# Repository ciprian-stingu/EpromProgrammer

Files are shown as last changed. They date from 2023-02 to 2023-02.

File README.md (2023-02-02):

# EpromProgrammer
2716 through 27080 Eprom Programmer

A programmer for EPROMs with capacities between 2KiB (2716 series) and 1MiB (27C080 series).  
It uses an Arduino NANO and few other components.  
As a starting point I used the excelent [arduino_eprom27_programmer](https://github.com/walhi/arduino_eprom27_programmer) project

## Main features
* It supports a large number of EPROMs with different capacities
* 2 programming speeds (normal & fast). Fast programming speed is available if you configure the VCC correctly
* On fast programming alghoritm, writing a 27C040 EPROM takes around 290 seconds
* Error detection on writing
* Additional verify option

## Hardware
All the files which you need in order to create the PCBs are in the [hardware](hardware) folder.

## Case
The files for 3D printing a case are available in [FreeCAD](FreeCAD) folder

## Limitations in current implementation
* No Windows support, but it should be easy to implement

## Supported EPROMs
```
//------------- 2716 -------------
2716 - Generic, 2716 - AMD, ET2716, HN462716, 2716 - Intel, M2716, M5L2716K, MBM2716, MCM2716, uPD2716
//------------- 27C16 -------------
27C16 - Generic, 27C16 - National, AM2716B, NMC27C16B
//------------- 2732 -------------
2732 - Generic, AM2732, AM9732, F2732, HN462732, 2732A, M2732A, MBM2732, NTE2732A, TMM2732D, uPD2732A
//------------- 27C32 -------------
27C32 - Generic, AM2732B, NMC27C32B, WS57C43C
//------------- 2764 -------------
2764 - Generic, 2764A - Intel, M2764A, M5L2764K, NTE2764, TMM2764AD
//------------- 27C64 -------------
27C64 - Generic, 27C64 - Microchip, Cy7C266, MBM27C64, NMC27C64, TMS27C64
//------------- 27128 -------------
27128 - Generic, HN4827128G, HN27128, M27128A - Intel, M27128A - ST, M5L27128K, M5M27C128K, MBM27128, NTE21128, TMM27128AD, TMS27128, uPD27128
//------------- 27C128 -------------
27C128 - Generic, 27C128 - Microchip, AM27C128, AT27C128, CY27C128, LH57126, M27C128, MSM27C128, NM27C128 - Fairchild, NM27C128 - National, QP27C128, SMJ27C128, TMS27C128
//------------- 27256 -------------
27256 - Generic, A68C256, AT27256, 27256 - Intel, M5L27256K, MBM27256, MSM27256, TMM27256, uPD27256
//------------- 27C256 -------------
27C256 - Generic, 27C256 - Microchip, AM27C256, AM27H256, CXK27C256DQ, CY27C256, CY27H256, CY7C274, EM27C256, FM27C256, HN27C256A, HN27C256AG, IS27C256, M27C256B, M5M27C256K, MBM27C256, 27HC256, MSM27C256H, NM27C256 - Fairchild, NM27C256 - National, NM27LC256, NMC27C256, NMC87C257, NPX27C256, QP27C256, 27C256 - SEEQ, M27C256 - SEEQ, SMJ27C256 - ASI, SMJ27C256 - TI, SPM27C256, TC57256, TMS27C256, TMS87C257, uPD27C256
//------------- 27512 -------------
27512 - Generic, 27512 - Intel, AM27512, HN27512, M27512, M5L27512K, MSM27512, TMM27512AD
//------------- 27C512 -------------
27C512 - Generic, 27C512 - Microchip, 27C512 - Intel, 27C512 - Philips, AM27C512, CXK27C512DQ, CY27C512, CY27H512, EM27C512, FM27C512, HN27C512, IS27HC512, MBM27C512, MX27C512, NM27C512, NM27P512, SMJ27C512 - ASI, SMJ27C512 - TI, TC57512AD, TMS27C512, uPD27C512
//------------- 27C010 -------------
27C010 - Generic, AM27C010, AM27H010, AM27HB010, CY27C010, CY27H010, 27C010 - Intel, EM27C010, FM27C010, HN27C101, IS27C010, M5M27C101K, NM27C010 - Fairchild, NM27C010 - National, NMC27C010, SMJ27C010 - ASI, SMJ27C010 - TI, TMS27C010
//------------- 27C1001 -------------
27C1001 - Generic, CXK27C1001DQ, M27C1001, MBM27C1001, MSM27C1000, MX27C1000, TC57C1001, TC57H1001
//------------- 27C020 -------------
27C020 - Generic, AM27C020, CY27C020, 27C020 - Intel, EM27C020, IS27C020, NM27C020, TMS27C020
//------------- 27C2001 -------------
27C2001 - Generic, M27C2001, MSM27C2000, uPD27C2001
//------------- 27C040 -------------
27C040 - Generic, AM27C040, CY27C040, EM27C040, FM27C040, 27C040 - Intel, NM27C040, NXP27C040, SMJ27C040 - ASI, SMJ27C040 - Micross, SMJ27C040 - TI, TMS27C040
//------------- 27C4001 -------------
27C4001 - Generic, HN27C4001, M27C4001, MBM27C4001, MSM27C401, MX27C4000, TC57C4000, uPD27C4001
//------------- 27C080 -------------
27C080 - Generic, AM27C080, AT27LV080, M27C801, MX27C8000
```

## Programmer images
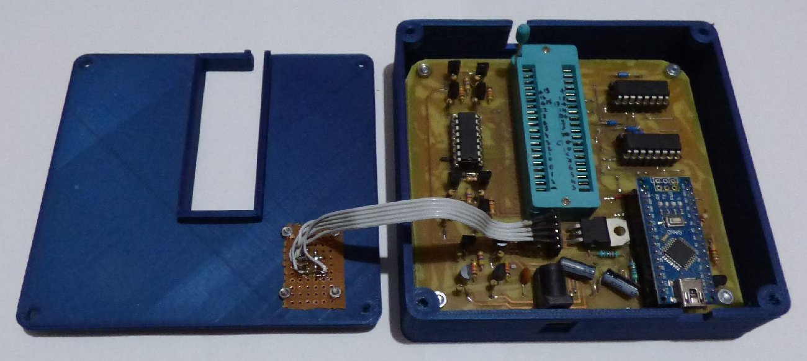
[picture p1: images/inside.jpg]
Inside
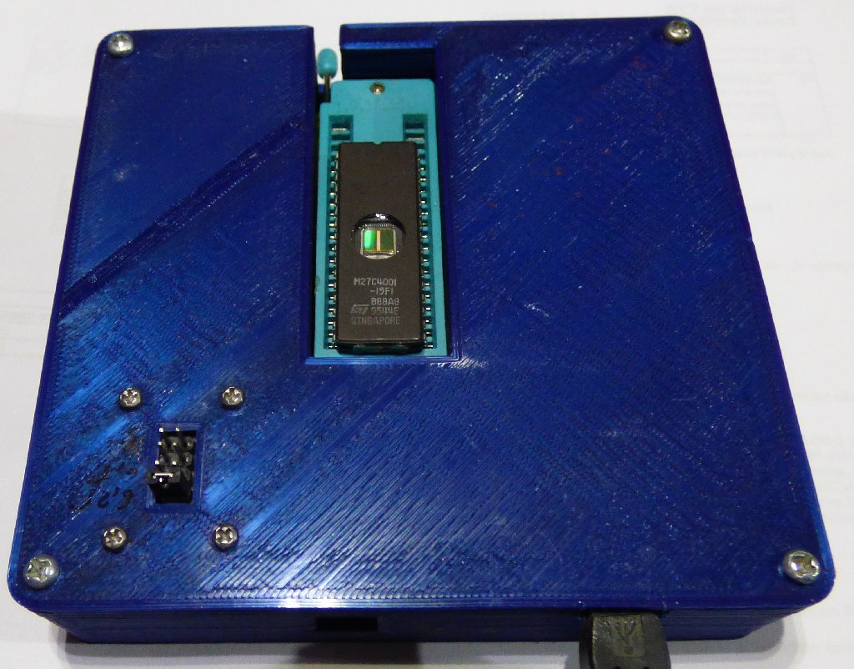
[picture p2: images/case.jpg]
Assembled Programmer
 

## GUI images
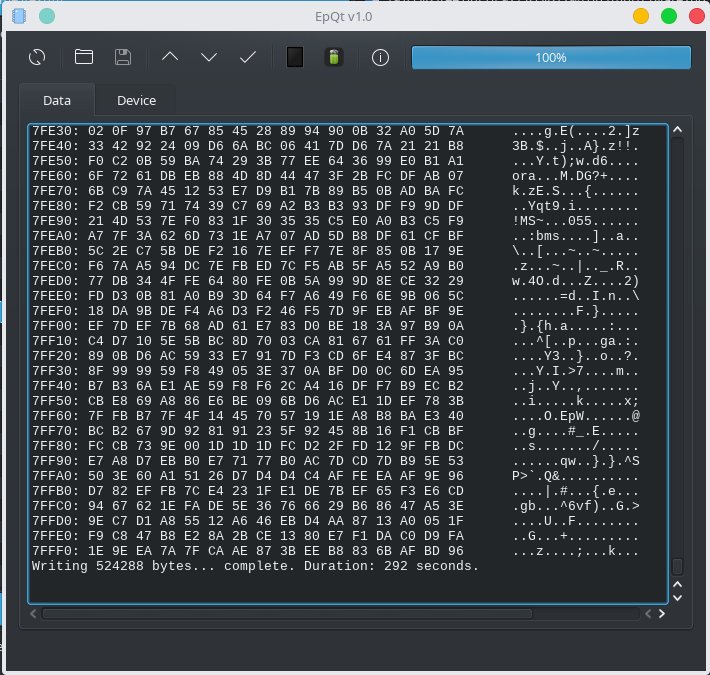
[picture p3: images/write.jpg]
Write
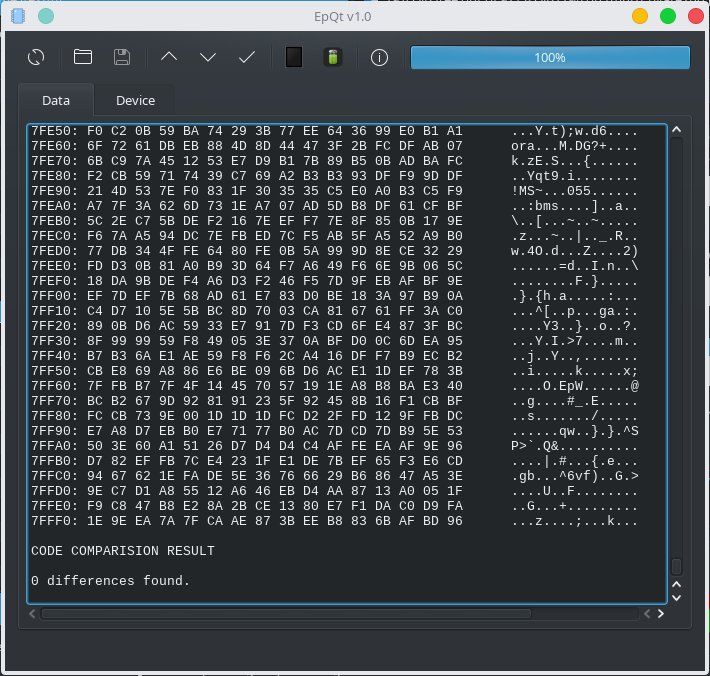
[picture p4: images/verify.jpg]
Verify
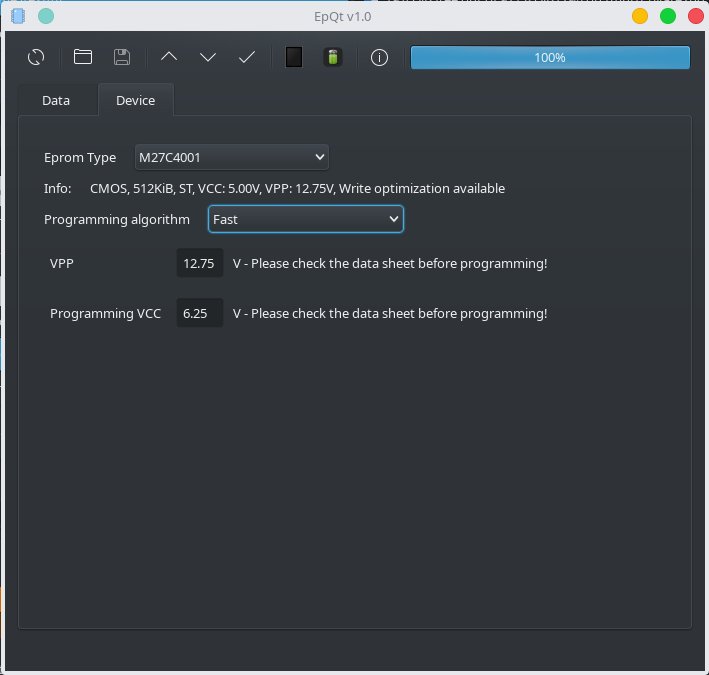
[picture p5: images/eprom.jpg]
EPROM options


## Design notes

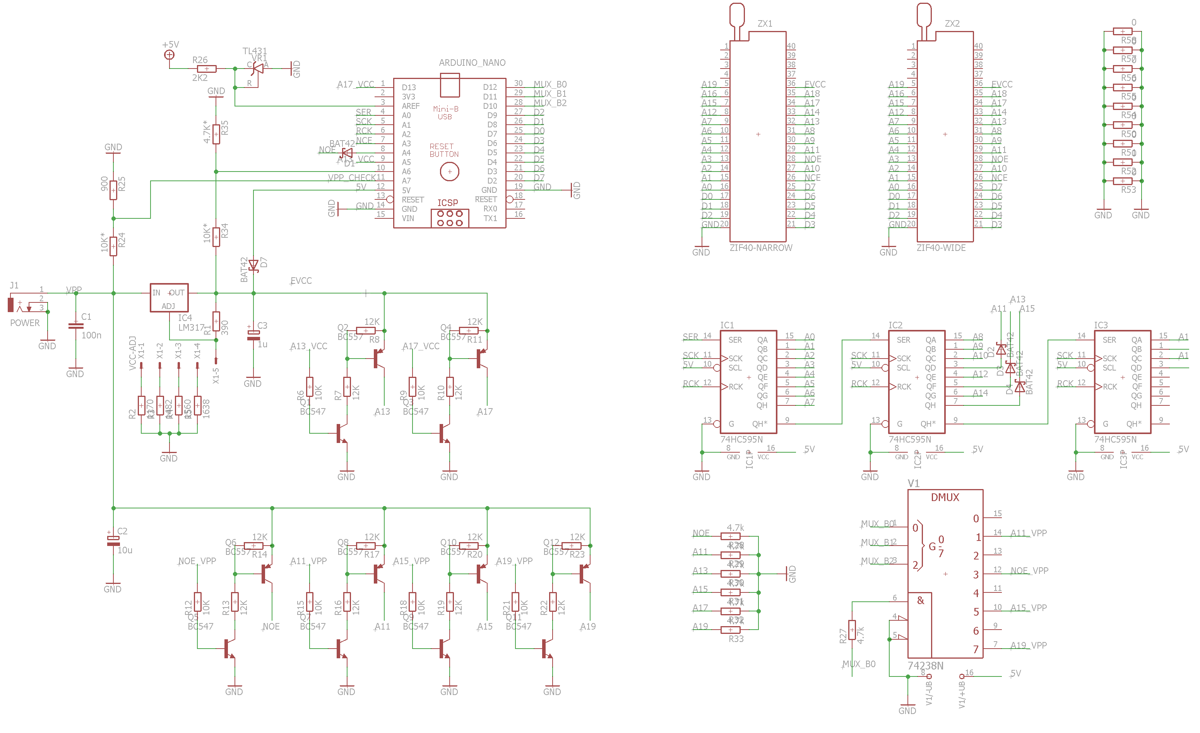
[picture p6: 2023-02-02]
hardware/schematic.png

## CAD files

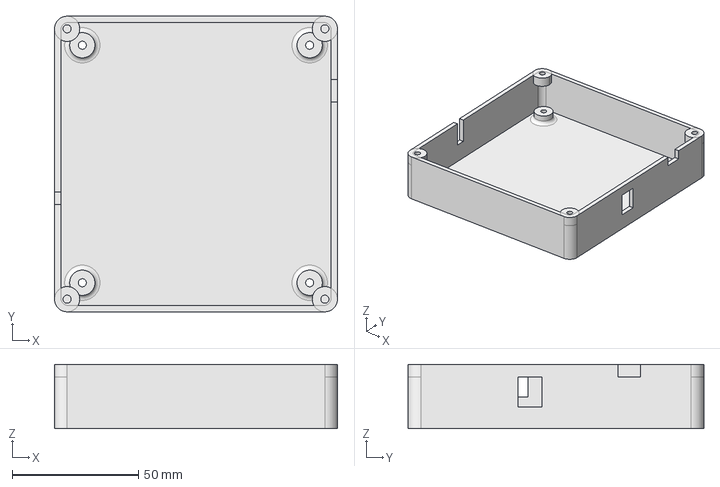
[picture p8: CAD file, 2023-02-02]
FreeCAD/case.FCStd
112.0 x 117.0 x 25.5 mm

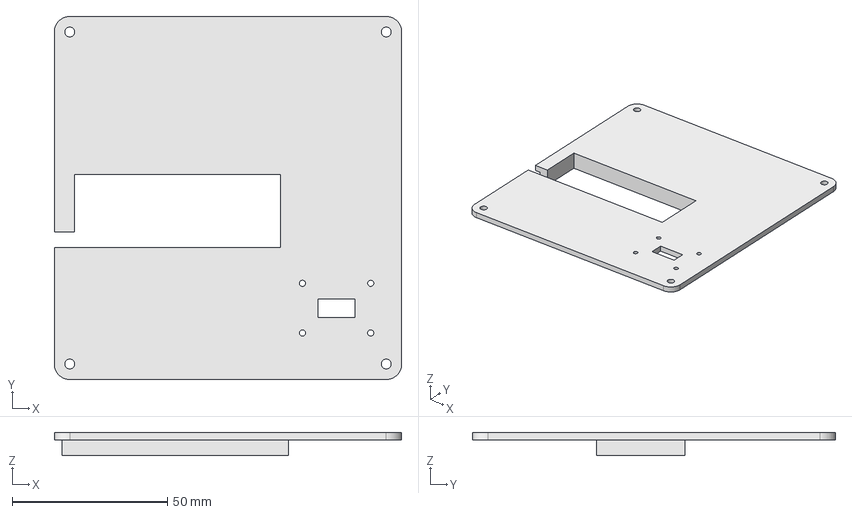
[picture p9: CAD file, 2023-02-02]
FreeCAD/lid.FCStd
112.0 x 117.0 x 7.50 mm

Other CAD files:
FreeCAD/case.stl
FreeCAD/lid.stl

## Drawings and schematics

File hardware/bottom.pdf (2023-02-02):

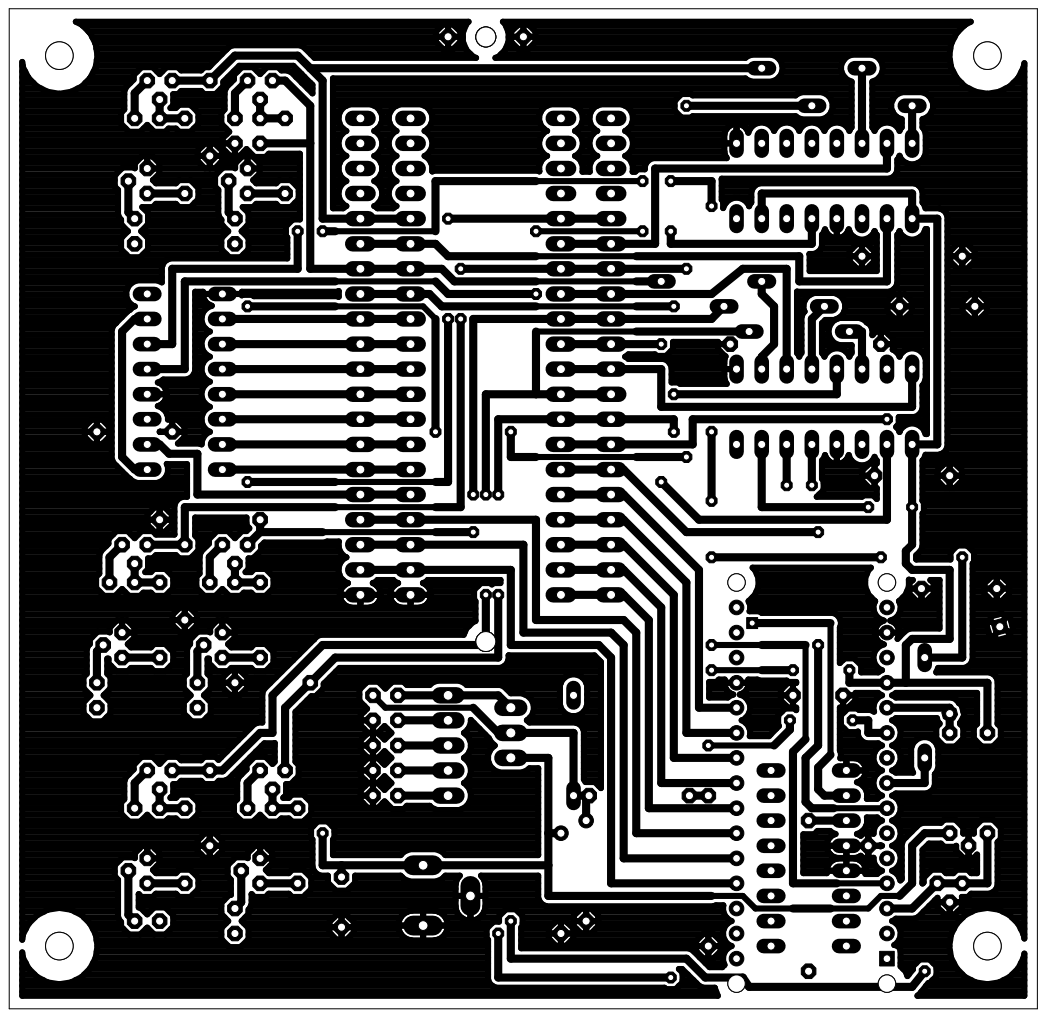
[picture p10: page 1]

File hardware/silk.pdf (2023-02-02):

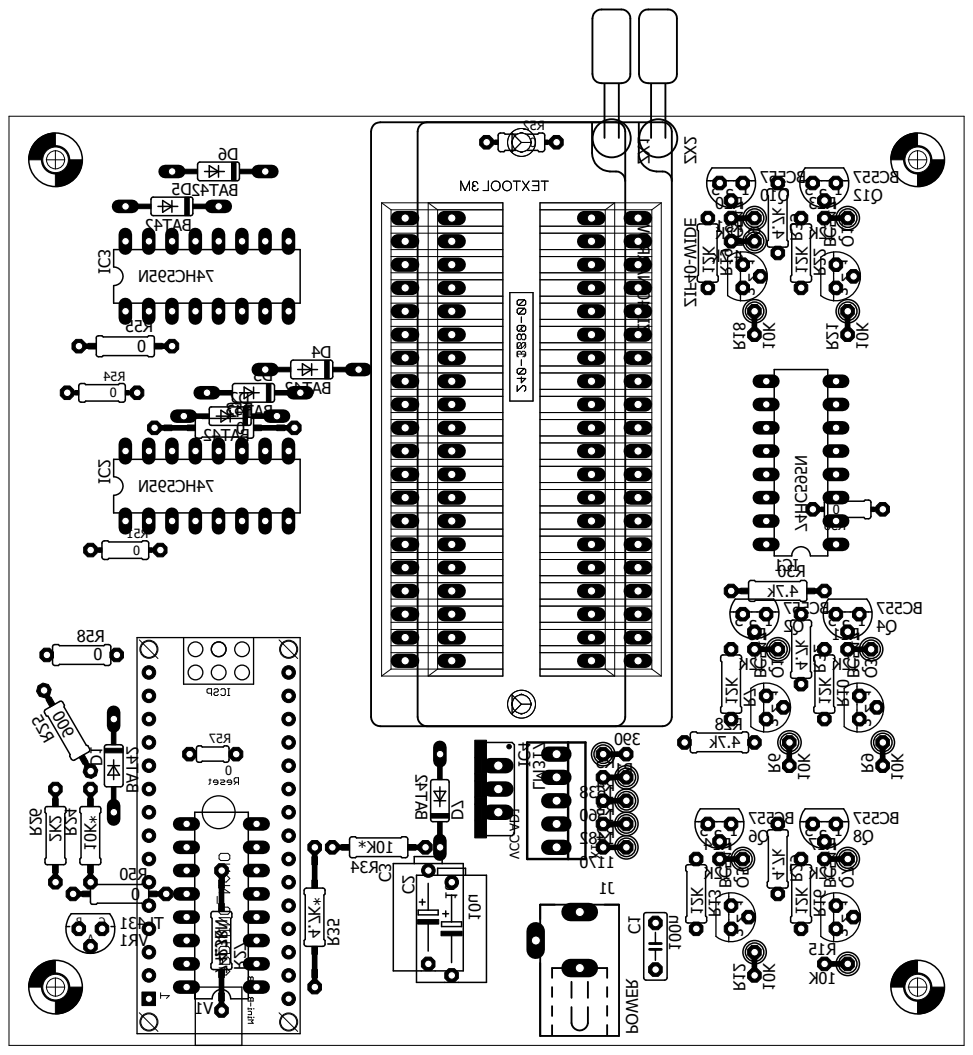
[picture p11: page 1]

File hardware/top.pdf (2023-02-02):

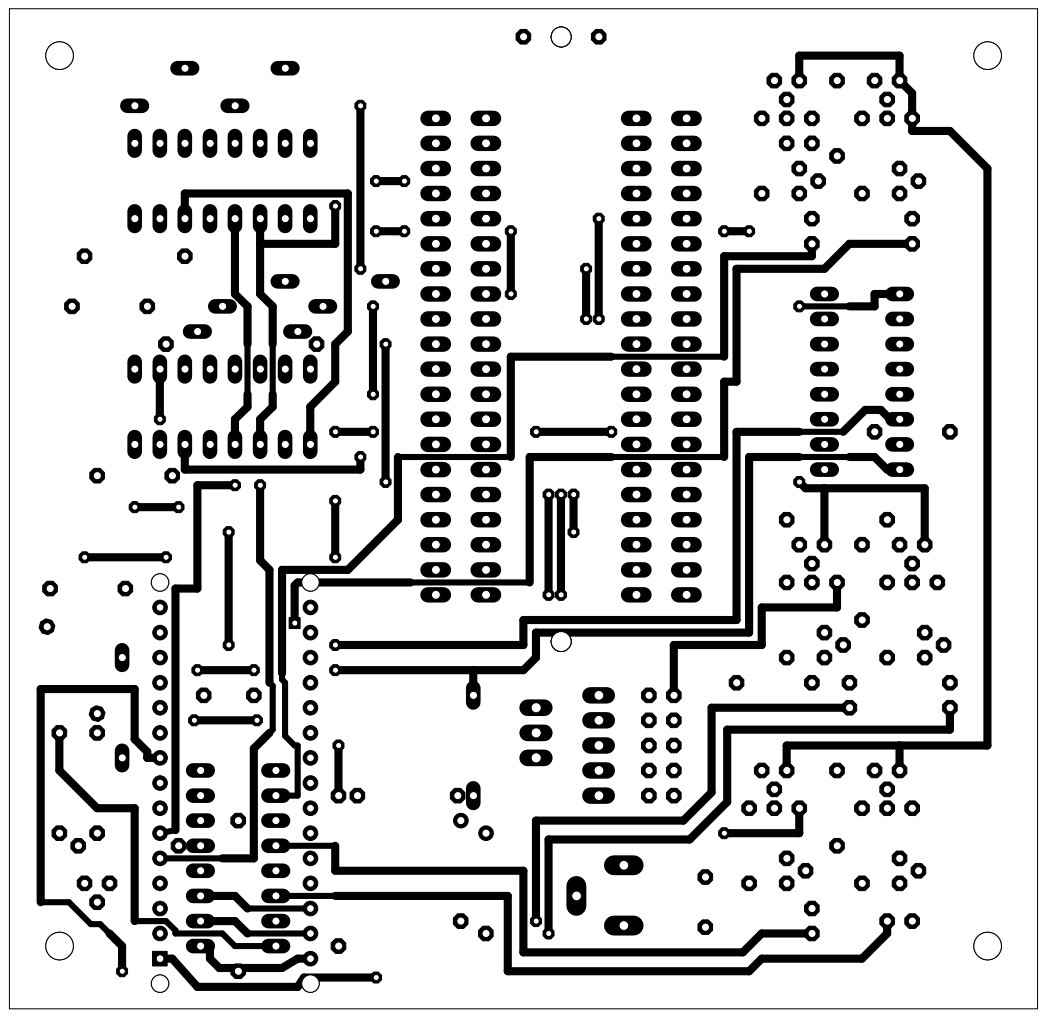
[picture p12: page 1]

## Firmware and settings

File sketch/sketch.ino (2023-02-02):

/**
 * 
 * Eprom Programmer
 * 
 * Copyright (C) 2021-2023 Ciprian Stingu
 * ciprian stingu at gmail dot com
 * 
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
 */
//------------------------------------------------------------------------------
#include "defines.h"
#include "io.h"
#include "write.h"
#include "read.h"
#include "test.h"
//------------------------------------------------------------------------------
// global variables
uint8_t SerialBufferStorage[SERIAL_BUF_LEN + 1];
uint8_t *SerialBuffer = SerialBufferStorage;
COMMAND_MODE CommandMode = COMMAND_MODE::WAIT;
EPROM_TYPE EpromSelected = EPROM_TYPE::NONE;
PRG_ALGO ProgrammingAlgorithm = PRG_ALGO::STANDARD;
double VppRequired = 0.0;
double VccRequired = 0.0;
uint32_t EpromEndAddress = 0; 
uint8_t EpromVppPin = 0;
//------------------------------------------------------------------------------

int8_t StringPos(uint8_t *bytes, const char *test, uint8_t offset = 0);
//------------------------------------------------------------------------------

void setup() 
{
  // set voltage reference to external
  analogReference(EXTERNAL);
  analogRead(VPP_TEST_PIN);
  analogRead(VCC_TEST_PIN);
    
  // 74HC595
  pinMode(SER_PIN, OUTPUT);
  pinMode(SCK_PIN, OUTPUT);
  pinMode(RCK_PIN, OUTPUT);

  pinMode(NCE_PIN, OUTPUT);
  pinMode(NOE_PIN, OUTPUT);
  pinMode(A13_VCC_PIN, OUTPUT);
  pinMode(A17_VCC_PIN, OUTPUT);

  // set mux output
  pinMode(MUX_B0_PIN, OUTPUT);
  pinMode(MUX_B1_PIN, OUTPUT);
  pinMode(MUX_B2_PIN, OUTPUT);
  
  InitializeEpromToAKnownState();

  SerialBuffer[SERIAL_BUF_LEN] = 0x00;
  
  Serial.begin(115200);
  Serial.println(F("27[C]XXXX programmer"));
  Serial.flush();

  CommandMode = COMMAND_MODE::WAIT;
}
//------------------------------------------------------------------------------

void loop() 
{
  switch(CommandMode)
  {
    case COMMAND_MODE::READ:
      if(EpromSelected == EPROM_TYPE::NONE)
      {
        Serial.print(F(RESPONSE_FLAG));
        Serial.print(F(RESPONSE_ERROR));
        Serial.println(F("No EPROM selected!"));
        Serial.flush();
        CommandMode = COMMAND_MODE::WAIT;
        break;
      }
      
      Serial.print(F(RESPONSE_FLAG));
      Serial.println(F(RESPONSE_READ_EPROM));
      Serial.flush();
      
      ReadEprom();

      Serial.print(F(RESPONSE_FLAG));
      Serial.println(F(RESPONSE_OK));
      Serial.flush();
      
      CommandMode = COMMAND_MODE::WAIT;
      break;
      
    case COMMAND_MODE::WRITE:
      if(EpromSelected == EPROM_TYPE::NONE)
      {
        Serial.print(F(RESPONSE_FLAG));
        Serial.print(F(RESPONSE_ERROR));
        Serial.println(F("No EPROM selected!"));
        Serial.flush();
        CommandMode = COMMAND_MODE::WAIT;
        break;
      }
      else if(VccRequired < MIN_VCC || VccRequired > MAX_VCC || VppRequired < MIN_VPP || VppRequired > MAX_VPP) 
      {
        Serial.print(F(RESPONSE_FLAG));
        Serial.print(F(RESPONSE_ERROR));
        Serial.println(F("Invalid VCC/VPP range specified!"));
        Serial.flush();
        CommandMode = COMMAND_MODE::WAIT;
        break;
      }
      else
      {
        double vccVoltage = GetVccVoltage();
        double vppVoltage = GetVppVoltage();
        if(vccVoltage < VccRequired - 0.25 || vccVoltage > VccRequired + 0.25)
        {
          Serial.print(F(RESPONSE_FLAG));
          Serial.print(F(RESPONSE_ERROR));
          Serial.print(F("Vcc: "));
          Serial.print(vccVoltage, 2);
          Serial.print(F("V != "));
          Serial.print(VccRequired, 2);
          Serial.println(F("V"));
          Serial.flush();
          CommandMode = COMMAND_MODE::WAIT;
          break;
        }
        if(vppVoltage < VppRequired - 0.25 || vppVoltage > VppRequired + 0.25)
        {
          Serial.print(F(RESPONSE_FLAG));
          Serial.print(F(RESPONSE_ERROR));
          Serial.print(F("Vpp: "));
          Serial.print(vppVoltage, 2);
          Serial.print(F("V != "));
          Serial.print(VppRequired, 2);
          Serial.println(F("V"));
          Serial.flush();
          CommandMode = COMMAND_MODE::WAIT;
          break;
        }
      }

      Serial.print(F(RESPONSE_FLAG));
      Serial.println(F(RESPONSE_WRITE_EPROM));
      Serial.flush();
      
      {
        if(ProgrammingAlgorithm == PRG_ALGO::STANDARD) {
           Serial.setTimeout(750);
        }
        else {
          Serial.setTimeout(400);
        }
        bool writeResult = WriteEprom();
        Serial.setTimeout(1000);
        EndWriteData();
        
        if(writeResult)
        {
          Serial.print(F(RESPONSE_FLAG));
          Serial.println(F(RESPONSE_WRITE_EPROM));
          Serial.flush();
        }
      }
      
      CommandMode = COMMAND_MODE::WAIT;
      break;
      
    case COMMAND_MODE::VOLTAGE:
      {
        double vccVoltage = GetVccVoltage();
        double vppVoltage = GetVppVoltage();

        Serial.print(F(RESPONSE_FLAG));
        Serial.print(F(RESPONSE_VOLTAGE_INFO));
        Serial.print(F("[VCC] "));
        Serial.print(vccVoltage, 2);
        Serial.print(F("|[VPP] "));
        Serial.println(vppVoltage, 2);
        Serial.flush();
      }
      CommandMode = COMMAND_MODE::WAIT;
      break;
      
    case COMMAND_MODE::TEST: //just to be sure
      if(EpromSelected != EPROM_TYPE::NONE)
      {
        Serial.print(F(RESPONSE_FLAG));
        Serial.print(F(RESPONSE_ERROR));
        Serial.println(F("EPROM is selected!"));
        Serial.flush();
        CommandMode = COMMAND_MODE::WAIT;
        break;
      }
      
      Serial.print(F(RESPONSE_FLAG));
      Serial.print(F(RESPONSE_TEST));
      Serial.println(F(" ON"));
      TestMode();
      Serial.print(F(RESPONSE_FLAG));
      Serial.print(F(RESPONSE_TEST));
      Serial.println(F(" OFF"));
      Serial.flush();
      CommandMode = COMMAND_MODE::WAIT;
      break;

    case COMMAND_MODE::TEST_SPEED: //just to be sure
      if(EpromSelected != EPROM_TYPE::NONE)
      {
        Serial.print(F(RESPONSE_FLAG));
        Serial.print(F(RESPONSE_ERROR));
        Serial.println(F("EPROM is selected!"));
        Serial.flush();
        CommandMode = COMMAND_MODE::WAIT;
        break;
      }
      
      Serial.print(F(RESPONSE_FLAG));
      Serial.print(F(RESPONSE_TEST));
      Serial.println(F(" SPEED ON"));
      TestSpeed();
      Serial.print(F(RESPONSE_FLAG));
      Serial.print(F(RESPONSE_TEST));
      Serial.println(F(" SPEED OFF"));
      Serial.flush();
      CommandMode = COMMAND_MODE::WAIT;
      break;
      
    default:
      if(!Serial.available()) {
        break;
      }

      for(uint8_t i = 0; i < SERIAL_BUF_LEN + 1; i++) {
        SerialBuffer[i] = 0x00;
      }
      
      uint8_t count = Serial.readBytes(SerialBuffer, SERIAL_BUF_LEN);
    
      while(Serial.available()) {
        Serial.read();
      }

      if(count)
      {
        bool commandFound = true;
        int8_t commandFlagIndex = StringPos(SerialBuffer, COMMAND_FLAG);
        
        if(commandFlagIndex != -1)
        {          
          int8_t commandTypeIndex = -1;
          
          if((commandTypeIndex = StringPos(SerialBuffer, COMMAND_SET_EPROM_TYPE, commandFlagIndex + 4)) != -1) 
          {
            String command((char*)SerialBuffer);
            String tmp = command.substring(commandTypeIndex + 4, commandTypeIndex + 6);
            int epromType = tmp.toInt();
            if(epromType >= EPROM_TYPE::NONE && epromType < EPROM_TYPE::LAST_EPROM_TYPE) {
              SelectEprom((EPROM_TYPE)epromType);
            }
            else
            {
              EpromSelected = EPROM_TYPE::NONE;
              commandFound = false;
            }
          }
          else if((commandTypeIndex = StringPos(SerialBuffer, COMMAND_READ_EPROM, commandFlagIndex + 4)) != -1) {
            CommandMode = COMMAND_MODE::READ;
          }
          else if((commandTypeIndex = StringPos(SerialBuffer, COMMAND_WRITE_EPROM, commandFlagIndex + 4)) != -1)
          {
            String command((char*)SerialBuffer);
            String tmp = command.substring(commandTypeIndex + 4, commandTypeIndex + 9);
            VccRequired = tmp.toFloat();
            if(VccRequired >= MIN_VCC && VccRequired <= MAX_VCC)
            {
              tmp = command.substring(commandTypeIndex + 9, commandTypeIndex + 14);
              VppRequired = tmp.toFloat();
              if(VppRequired >= MIN_VPP && VppRequired <= MAX_VPP)
              {
                tmp = command.substring(commandTypeIndex + 14, commandTypeIndex + 16);
                int testProgrammingAlgorithm = tmp.toInt();
                if(testProgrammingAlgorithm >= (int)PRG_ALGO::STANDARD && testProgrammingAlgorithm < (int)PRG_ALGO::LAST_ALGO) 
                {
                  CommandMode = COMMAND_MODE::WRITE;
                  ProgrammingAlgorithm = (PRG_ALGO)testProgrammingAlgorithm;
                }
                else 
                {
                  ProgrammingAlgorithm = PRG_ALGO::STANDARD;
                  VppRequired = 0;
                  VccRequired = 0;
                  commandFound = false;
                }
              }
              else
              {
                ProgrammingAlgorithm = PRG_ALGO::STANDARD;
                VppRequired = 0;
                VccRequired = 0;
                commandFound = false;
              }
            }
            else
            {
              ProgrammingAlgorithm = PRG_ALGO::STANDARD;
              VppRequired = 0;
              VccRequired = 0;
              commandFound = false;
            }
          }
          else if(StringPos(SerialBuffer, COMMAND_VOLTAGE_INFO, commandFlagIndex + 4) != -1) {
            CommandMode = COMMAND_MODE::VOLTAGE;
          }
          else if(StringPos(SerialBuffer, COMMAND_TEST, commandFlagIndex + 4) != -1) {
            CommandMode = COMMAND_MODE::TEST;
          }
          else if(StringPos(SerialBuffer, COMMAND_TEST_SPEED, commandFlagIndex + 4) != -1) {
            CommandMode = COMMAND_MODE::TEST_SPEED;
          }
          else {
            commandFound = false;
          }
        }
        else {
          commandFound = false;
        }

        Serial.print(F(RESPONSE_FLAG));
        if(commandFound) {
          Serial.println(F(RESPONSE_OK));
        }
        else 
        {
          CommandMode = COMMAND_MODE::WAIT;
          Serial.print(F(RESPONSE_ERROR));
          Serial.print(F("["));
          Serial.write(SerialBuffer, SERIAL_BUF_LEN);
          Serial.println(F("]"));
        }
        Serial.flush();
      }
  }
}
//------------------------------------------------------------------------------

int8_t StringPos(uint8_t *bytes, const char *test, uint8_t offset)
{
  for(int8_t i = offset, j = SERIAL_BUF_LEN - 4; i < j; i++)
  {
    uint8_t k = 0;
    for(; k < 4; k++)
    {
      if(bytes[i] != (uint8_t)test[k]) {
        break;    
      }
      i++;
    }
    if(k == 4) {
      return i - k;
    }
  }
  return -1;
}
//------------------------------------------------------------------------------

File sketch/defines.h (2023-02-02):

/**
 * 
 * Eprom Programmer
 * 
 * Copyright (C) 2021-2023 Ciprian Stingu
 * ciprian stingu at gmail dot com
 * 
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
 */
//------------------------------------------------------------------------------
#pragma once

#include <Arduino.h>
//------------------------------------------------------------------------------

#define OPTIMIZE_FOR_SPEED

// 74HC595
#define SER_PIN A0
#define SCK_PIN A1
#define RCK_PIN A2

// Data
#define D0_PIN 7
#define D1_PIN 8
#define D2_PIN 9
#define D3_PIN 6
#define D4_PIN 5
#define D5_PIN 4
#define D6_PIN 3
#define D7_PIN 2

// Eprom control
#define NCE_PIN     A3
#define NOE_PIN     A4
#define A13_VCC_PIN A5
#define A17_VCC_PIN 13
#define NO_VCC_PIN  0
#define MUX_B0_PIN  12
#define MUX_B1_PIN  11
#define MUX_B2_PIN  10
#define A11_VPP_PIN 1
#define NOE_VPP_PIN 3
#define A15_VPP_PIN 5
#define A19_VPP_PIN 7
#define NO_VPP_PIN  0

// Voltage test
#define VPP_TEST_PIN    A7
#define VPP_R_PWR_VALUE 9944.0
#define VPP_R_GND_VALUE 894.0
#define VCC_TEST_PIN    A6
#define VCC_R_PWR_VALUE 9974.0
#define VCC_R_GND_VALUE 4662.0
#define AREF_VALUE      2.466

#define SERIAL_BUF_LEN 32
#define TEST_STEP_WAIT 2500
#define VOLTAGE_CHECKS 250

#define MIN_VCC 4.50
#define MAX_VCC 6.50
#define MIN_VPP 10.00
#define MAX_VPP 30.00

// commands
#define COMMAND_FLAG           "@CMD"
#define COMMAND_SET_EPROM_TYPE "TYPE"
#define COMMAND_VOLTAGE_INFO   "VINF"
#define COMMAND_READ_EPROM     "READ"
#define COMMAND_WRITE_EPROM    "WRIT"
#define COMMAND_TEST           "TEST"
#define RESPONSE_FLAG          "@RSP"
#define RESPONSE_OK            "OK  "
#define RESPONSE_ERROR         "ERR "
#define RESPONSE_BLOCK         "BLCK"
#define RESPONSE_READ_EPROM    COMMAND_READ_EPROM
#define RESPONSE_VOLTAGE_INFO  COMMAND_VOLTAGE_INFO
#define RESPONSE_TEST          COMMAND_TEST
#define RESPONSE_WRITE_EPROM   COMMAND_WRITE_EPROM
#define COMMAND_TEST_SPEED     "SPED"

enum COMMAND_MODE {
  WAIT,
  READ,
  WRITE,
  VOLTAGE,
  TEST,
  TEST_SPEED
};

enum EPROM_TYPE {
  NONE = 0,
  X16  = 1,  // 2716
  C16  = 2,  // 27C16
  X32  = 3,  // 2732
  C32  = 4,  // 27C32
  X64  = 5,  // 2764
  C64  = 6,  // 27C64
  X128 = 7,  // 27128
  C128 = 8,  // 27C128
  X256 = 9,  // 27256
  C256 = 10, // 27C256
  X512 = 11, // 27512
  C512 = 12, // 27C512
  C010 = 13, // 27C010
  C1D1 = 14, // 27C1001
  C020 = 15, // 27C020
  C2D1 = 16, // 27C2001
  C040 = 17, // 27C040
  C4D1 = 18, // 27C4001
  C080 = 19, // 27C080
  LAST_EPROM_TYPE
};

enum PRG_ALGO {
  UNDEFINED        = 0,
  STANDARD         = 1,
  FAST             = 2,
  LAST_ALGO
};
//------------------------------------------------------------------------------

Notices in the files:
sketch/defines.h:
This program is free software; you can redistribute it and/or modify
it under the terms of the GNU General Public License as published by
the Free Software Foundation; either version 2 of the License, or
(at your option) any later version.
